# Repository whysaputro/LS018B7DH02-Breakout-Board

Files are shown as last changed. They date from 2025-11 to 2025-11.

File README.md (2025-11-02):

# LS018B7DH02-Breakout-Board



Breakout board for the **Sharp Memory LCD – LS018B7DH02**. This repository contains **schematics** and **PCB layout** built with **KiCad**, plus fabrication outputs (Gerbers) so you can order boards, assemble, and test quickly.

> **Note:** The LS018B7DH02 is a low-power memory LCD with a simple SPI-like interface. Always verify pinout and operating voltages against the official datasheet for your specific panel.

---
# License
This project is licensed under the **MIT License**.
 
---
# Disclaimer
Design is provided **as-is**, without warranty. Validate against the official **LS018B7DH02 datasheet** and thoroughly test before production.

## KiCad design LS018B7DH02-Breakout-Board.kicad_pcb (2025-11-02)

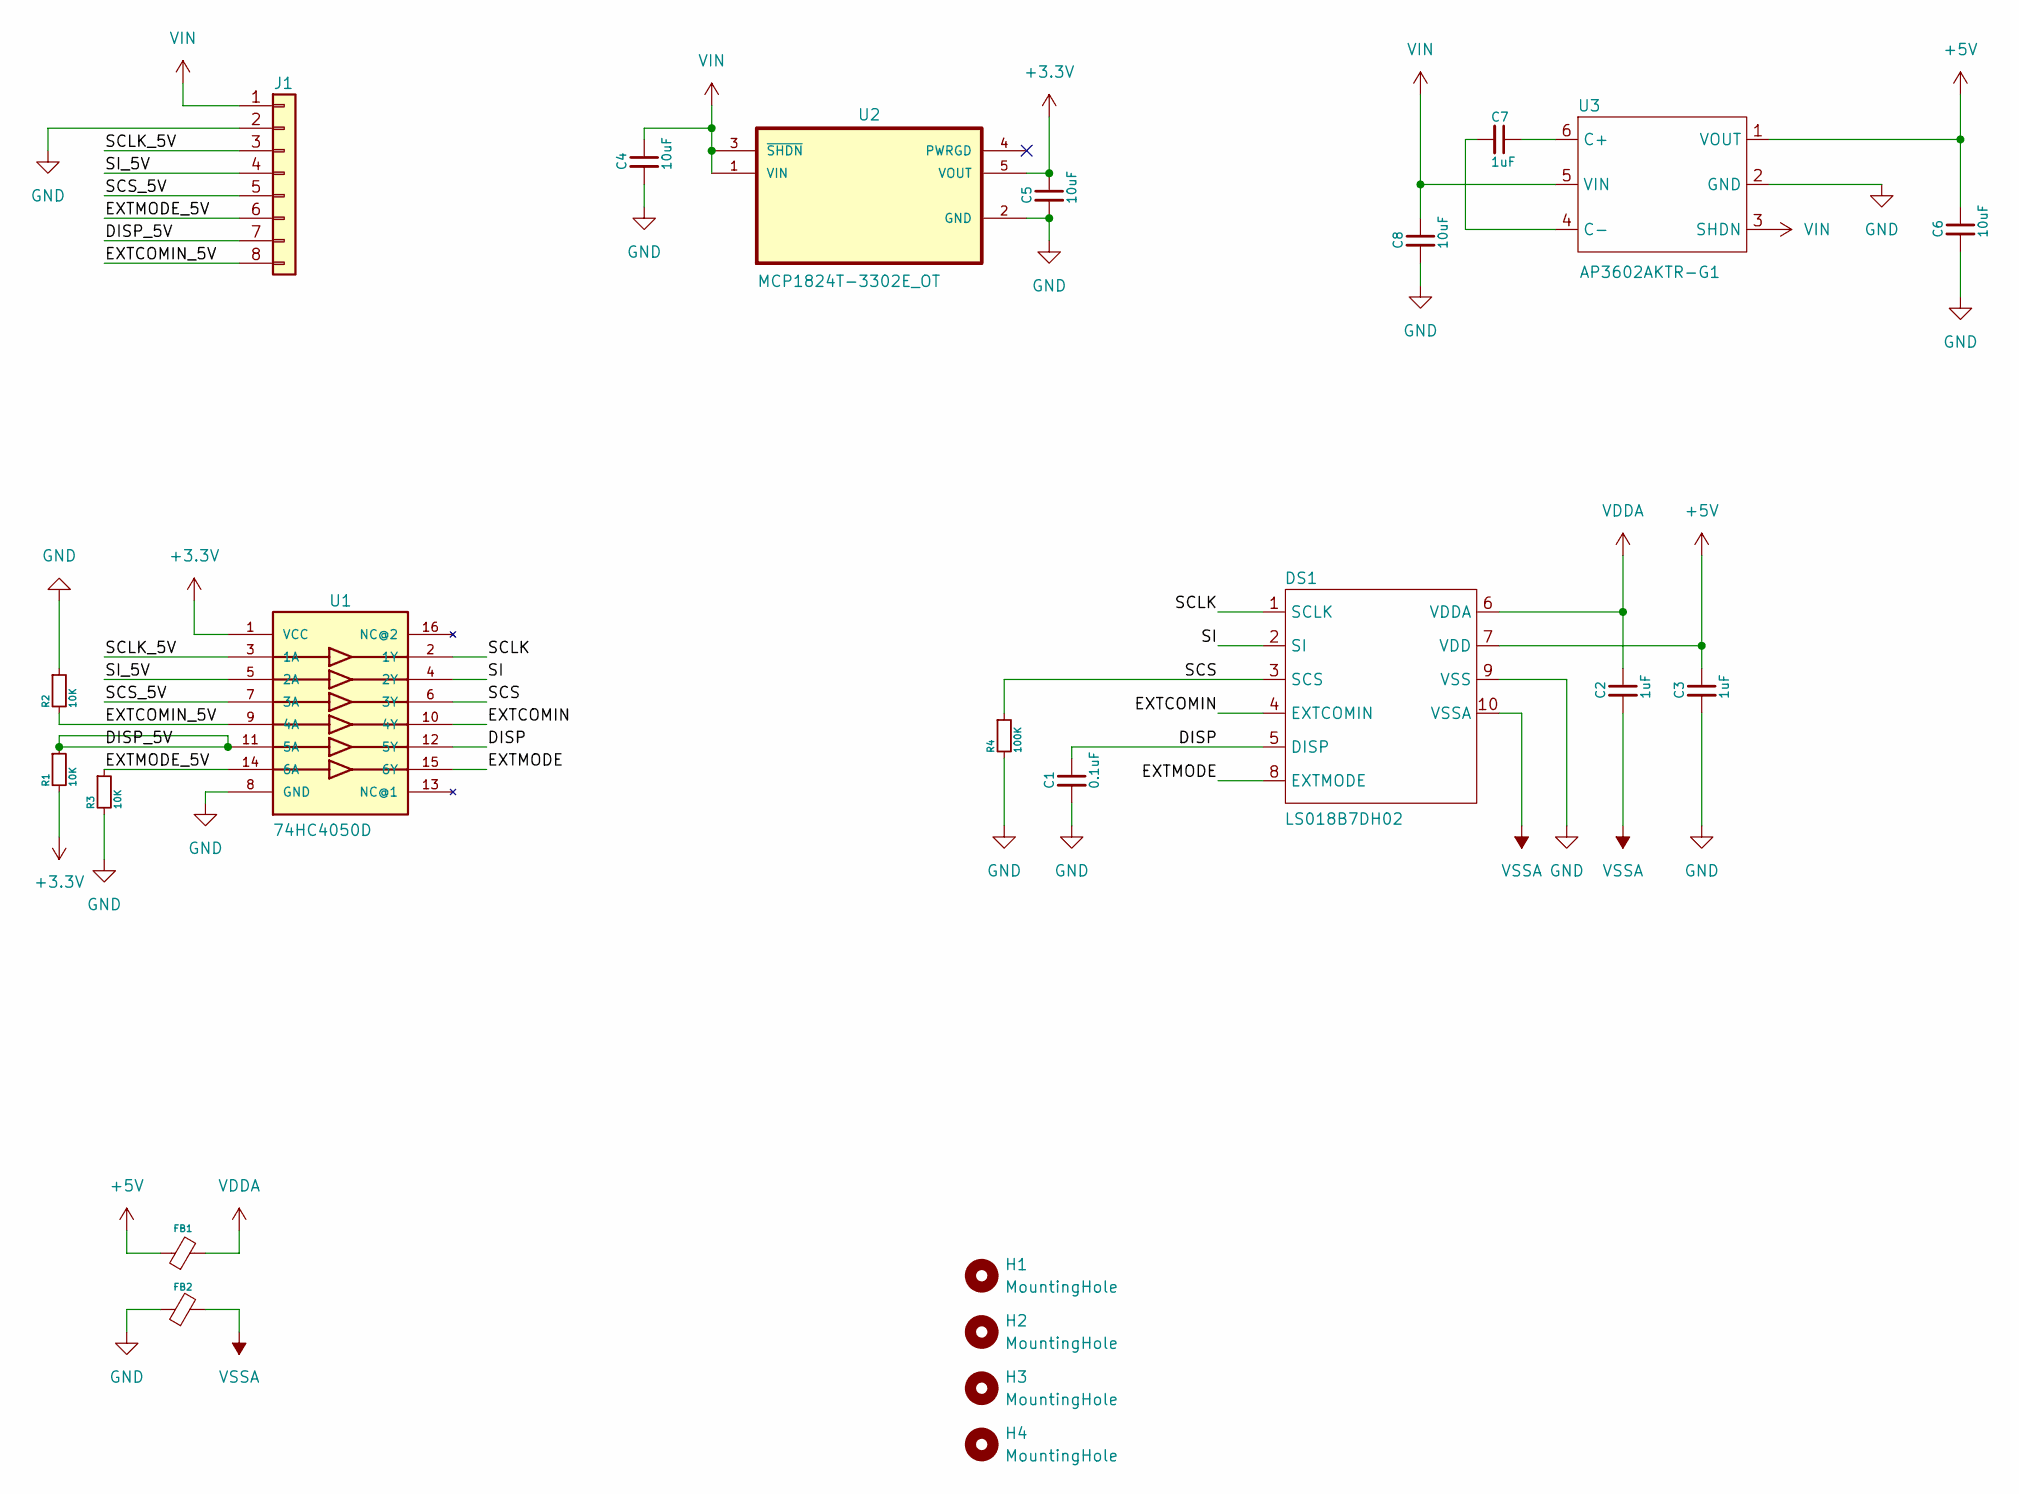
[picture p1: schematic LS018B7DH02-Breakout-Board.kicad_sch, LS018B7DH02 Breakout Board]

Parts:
C1: 0.1uF; C_0805_2012Metric_Pad1.18x1.45mm_HandSolder
C2, C3, C7: 1uF; C_0805_2012Metric_Pad1.18x1.45mm_HandSolder
C4, C5, C6, C8: 10uF; C_0805_2012Metric_Pad1.18x1.45mm_HandSolder
DS1: LS018B7DH02; MOLEX_5034801000
FB1, FB2: FerriteBead_Small; L_0805_2012Metric_Pad1.15x1.40mm_HandSolder
H1, H2, H3, H4: MountingHole; MountingHole_3.2mm_M3
J1: Conn_01x08; JST_PH_S8B-PH-SM4-TB_1x08-1MP_P2.00mm_Horizontal
R1, R2, R3: 10K; R_0805_2012Metric_Pad1.20x1.40mm_HandSolder
R4: 100K; R_0805_2012Metric_Pad1.20x1.40mm_HandSolder
U1: 74HC4050D; SO16
U2: MCP1824T-3302E_OT; SOT95P280X145-5N
U3: AP3602AKTR-G1; SOT95P280X145-6N

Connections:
+3.3V: C5.1, R1.2, U1.1 (VCC), U2.5 (VOUT)
+5V: C3.1, C6.1, DS1.7 (VDD), FB1.1, U3.1 (VOUT)
/DISP: C1.1, DS1.5 (DISP), U1.12 (5Y)
/DISP_5V: J1.7, R1.1, U1.11 (5A)
/EXTCOMIN: DS1.4 (EXTCOMIN), U1.10 (4Y)
/EXTCOMIN_5V: J1.8, R2.2, U1.9 (4A)
/EXTMODE: DS1.8 (EXTMODE), U1.15 (6Y)
/EXTMODE_5V: J1.6, R3.1, U1.14 (6A)
/SCLK: DS1.1 (SCLK), U1.2 (1Y)
/SCLK_5V: J1.3, U1.3 (1A)
/SCS: DS1.3 (SCS), R4.1, U1.6 (3Y)
/SCS_5V: J1.5, U1.7 (3A)
/SI: DS1.2 (SI), U1.4 (2Y)
/SI_5V: J1.4, U1.5 (2A)
GND: C1.2, C3.2, C4.2, C5.2, C6.2, C8.2, DS1.9 (VSS), FB2.1, J1.2, R2.1, R3.2, R4.2, U1.8 (GND), U2.2 (GND), U3.2 (GND)
unnamed: C7.1, U3.6 (C+)
unnamed: C7.2, U3.4 (C-)
VDDA: C2.1, DS1.6 (VDDA), FB1.2
VIN: C4.1, C8.1, J1.1, U2.1 (VIN), U2.3 (~SHDN), U3.3 (SHDN), U3.5 (VIN)
VSSA: C2.2, DS1.10 (VSSA), FB2.2

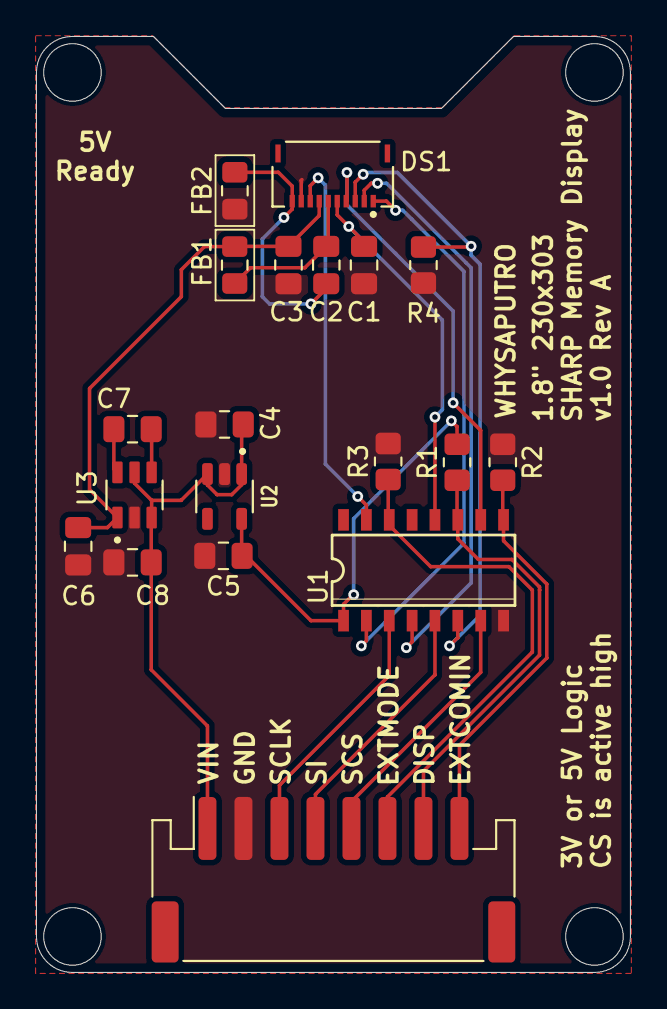
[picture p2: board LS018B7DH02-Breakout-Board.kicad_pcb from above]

Board: 2 copper layers, 33.0 x 52.0 mm, 23 parts (0 on the bottom side), 20 nets.

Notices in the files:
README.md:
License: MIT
